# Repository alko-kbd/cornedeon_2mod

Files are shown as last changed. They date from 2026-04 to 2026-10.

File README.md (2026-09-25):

# Cornedeon v2mod Keyboard

Modular Cornedeon split keyboard.

Keyboard Maintainer: [alko](https://github.com/alko-kbd/cornedeon_2mod) [alko-kbd@alk0.ru](mailto:alko-kbd@alk0.ru)

Web Site: [cornedeon.ru](https://cornedeon.ru)

Hardware Supported: Handwired, RP2040, Trackpads, Trackpoints, Joystick.

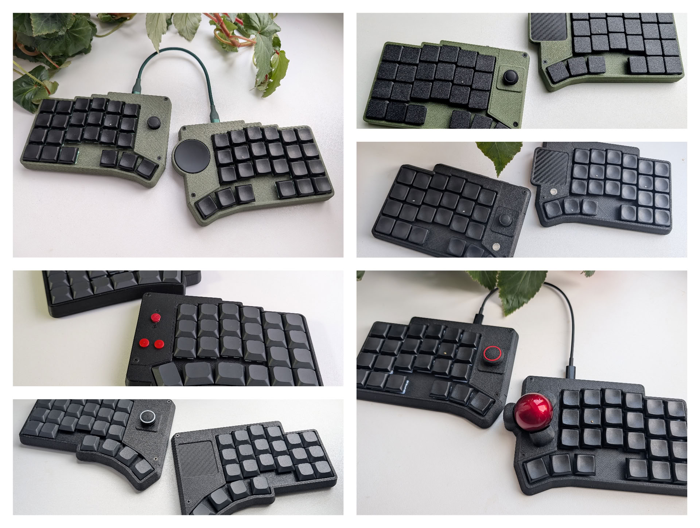
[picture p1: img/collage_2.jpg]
Cornedeon 2MOD


**Revision 2mod**

Support for custom modules on same case, as trackpoint, trackpad, trackball, encoders, joystick etc.

**Build**

#>git clone --recurse-submodules https://github.com/vial-kb/vial-qmk.git

Prepare [build environment](https://get.vial.today/docs/porting-to-vial.html).

Clone this repository to vial-qmk/keyboards/alko.

#>qmk compile -kb alko/cornedeon_2mod -km vial

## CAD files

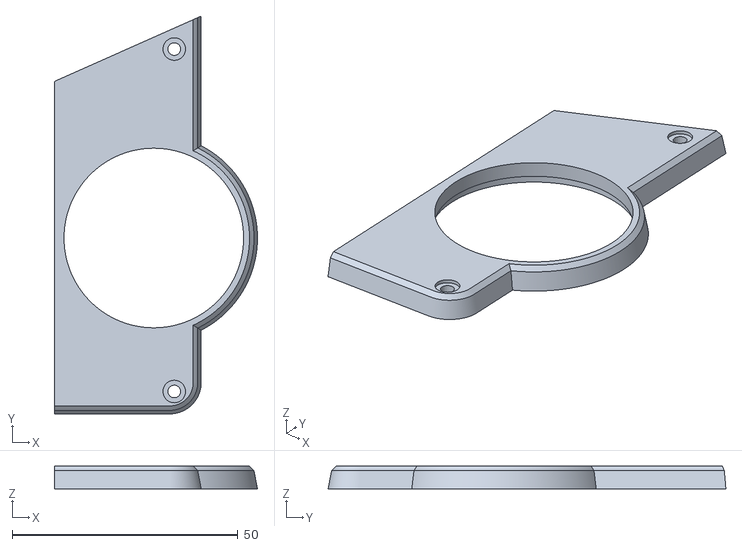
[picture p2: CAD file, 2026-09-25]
case/v3_cirque/cornedeon_2m_choc_cirque_right.stl
45.0 x 88.1 x 5.00

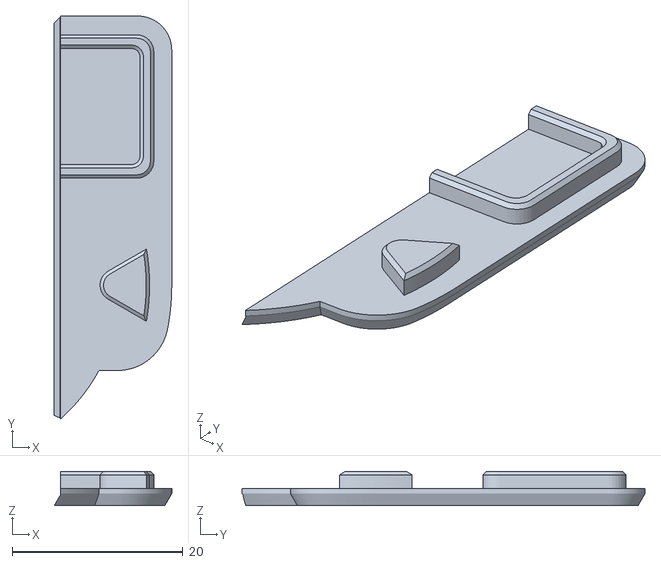
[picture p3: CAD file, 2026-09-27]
case/v4_joy_tps43_tball/cornedeon_2m_tball_stub_v2.stl
13.8 x 47.2 x 4.00

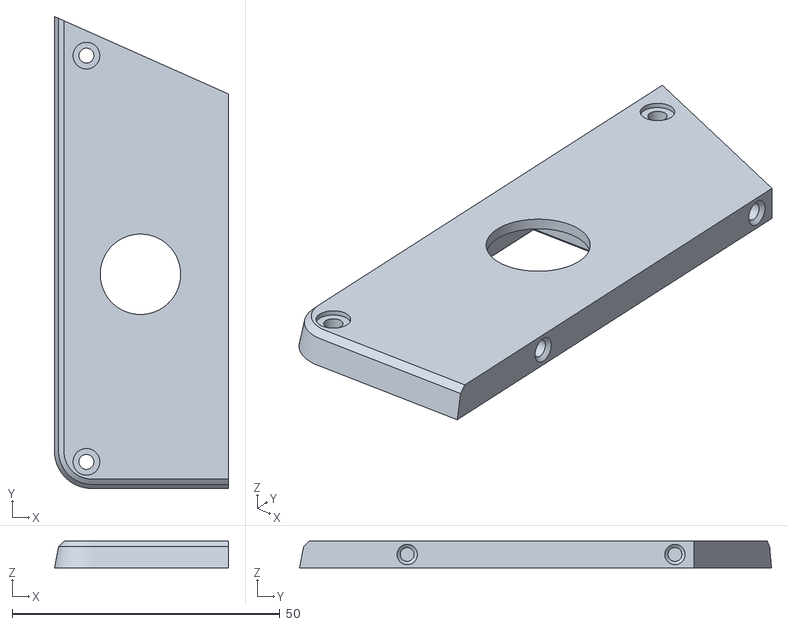
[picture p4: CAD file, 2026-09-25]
case/v3_cirque/cornedeon_2m_choc_switch_left.stl
32.5 x 88.1 x 5.00

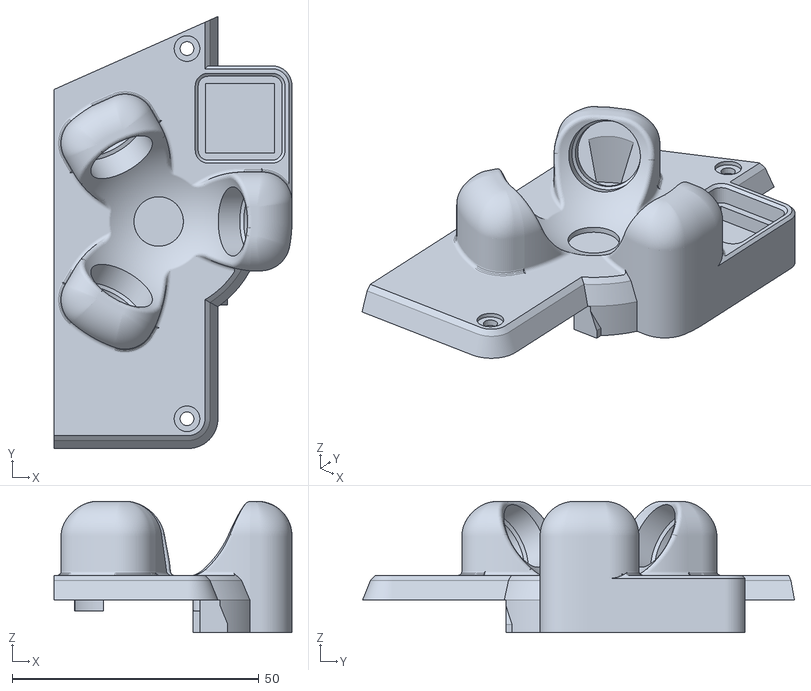
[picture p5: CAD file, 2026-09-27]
case/v4_joy_tps43_tball/cornedeon_2m_tball_v2_right.stl
48.2 x 87.5 x 26.6

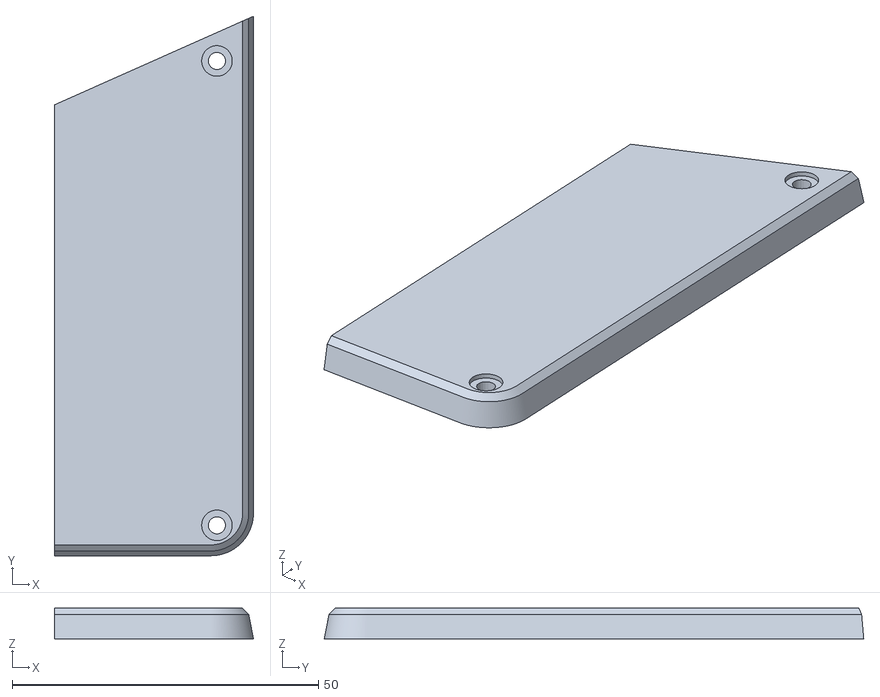
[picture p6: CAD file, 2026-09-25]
case/v3_cirque/cornedeon_2m_choc_stub_right.stl
32.5 x 88.1 x 5.00

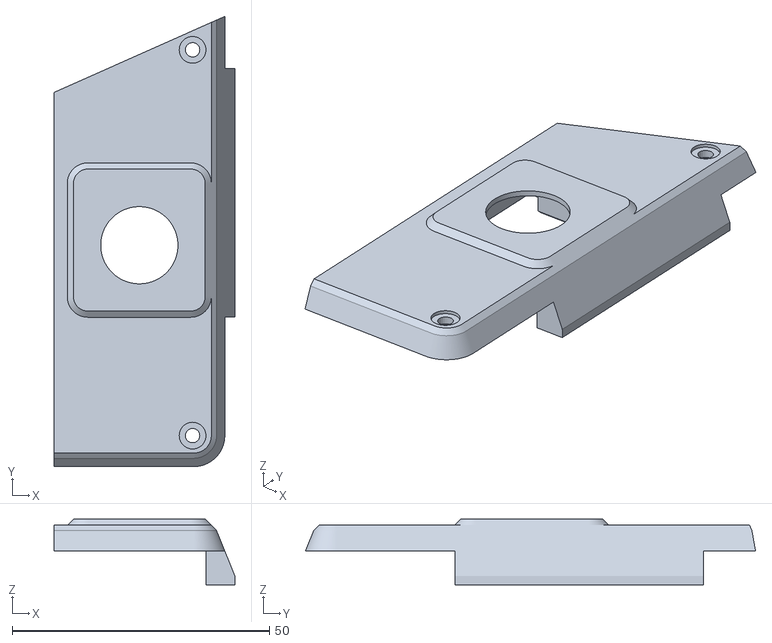
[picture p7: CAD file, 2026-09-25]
case/v4_joy_tps43_tball/cornedeon_2m_joy_left.stl
35.2 x 87.5 x 12.8

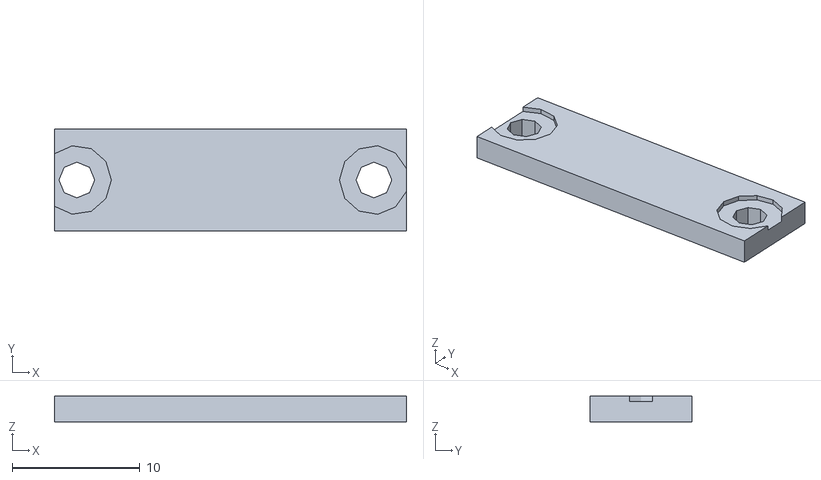
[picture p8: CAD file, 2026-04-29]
case/v3_cirque/switch_bar.stl
27.6 x 8.00 x 2.00

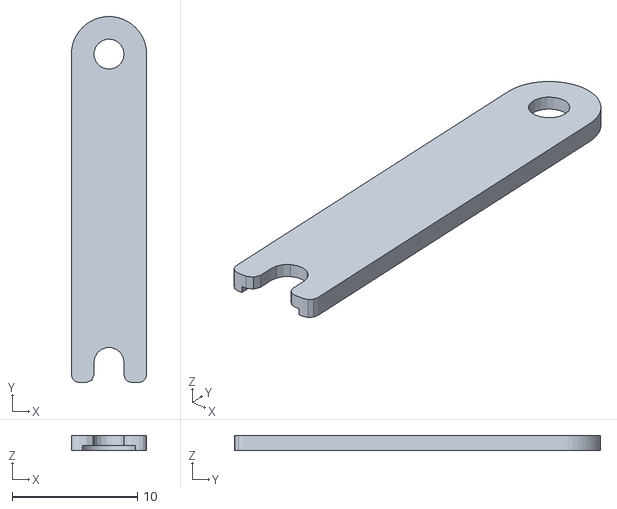
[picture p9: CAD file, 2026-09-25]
case/v4_joy_tps43_tball/joy_bar.stl
6.00 x 29.2 x 1.20

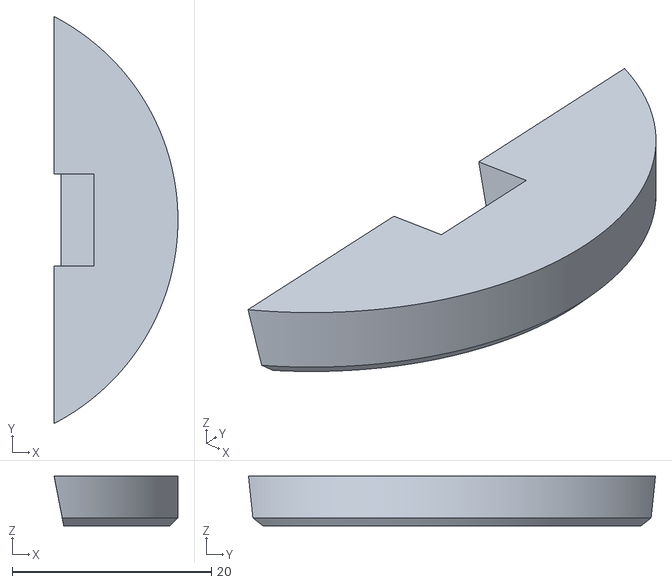
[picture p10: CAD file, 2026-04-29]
case/v3_cirque/cornedeon_2m_choc_cirque_bottom.stl
12.4 x 40.8 x 5.00

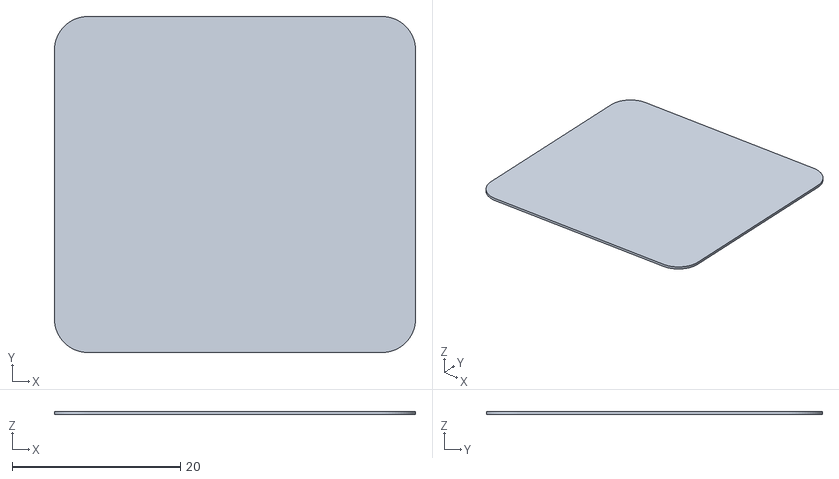
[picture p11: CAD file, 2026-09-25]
case/v4_joy_tps43_tball/tps43_pad.stl
43.0 x 40.0 x 0.4

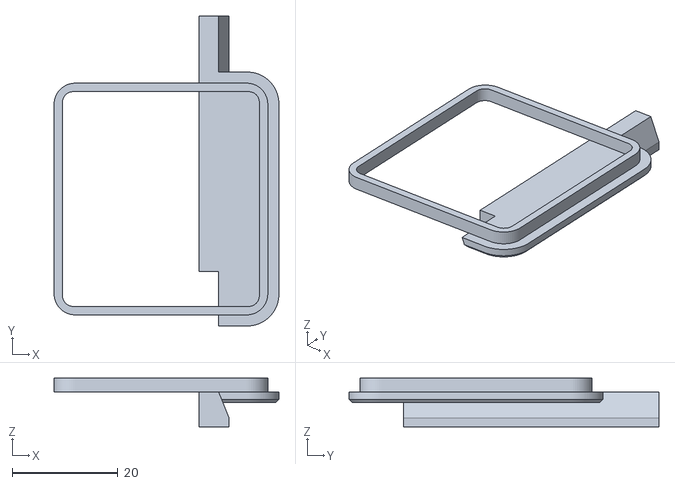
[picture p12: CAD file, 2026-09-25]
case/v4_joy_tps43_tball/cornedeon_2m_tps43_stub.stl
42.5 x 58.6 x 9.20

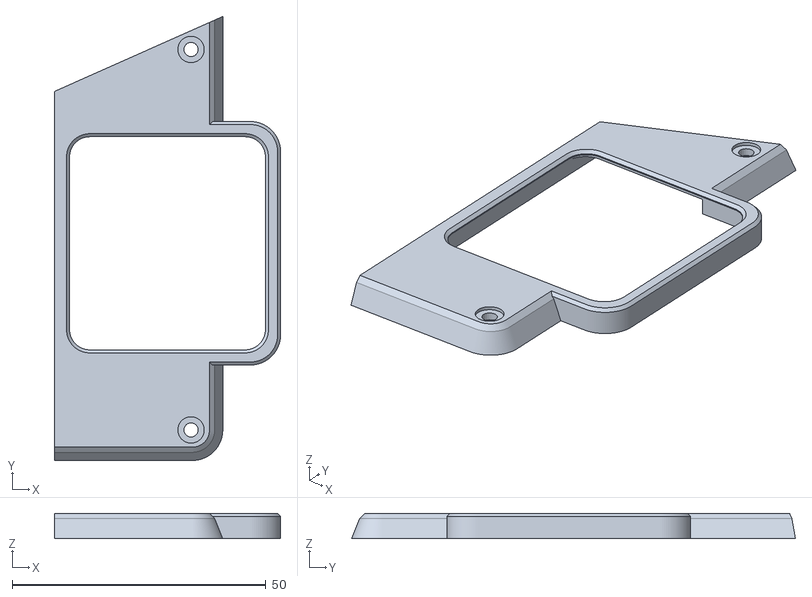
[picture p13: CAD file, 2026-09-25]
case/v4_joy_tps43_tball/cornedeon_2m_tps43.stl
44.6 x 87.5 x 5.00

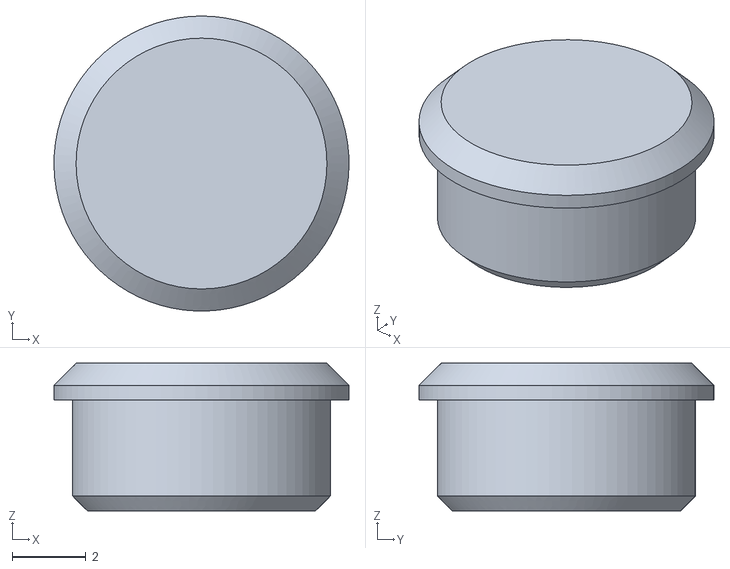
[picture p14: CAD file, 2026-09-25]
case/v4_joy_tps43_tball/led.stl
8.00 x 8.00 x 4.00

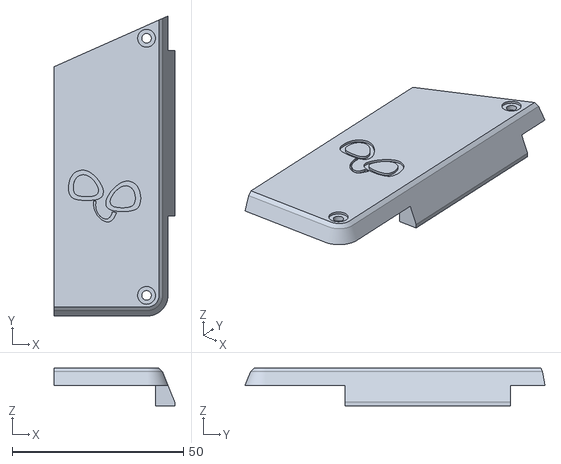
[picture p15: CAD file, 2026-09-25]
case/v4_joy_tps43_tball/cornedeon_2m_stub.stl
35.2 x 87.5 x 11.0

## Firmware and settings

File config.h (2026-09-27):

// Copyright 2024 QMK
// SPDX-License-Identifier: GPL-2.0-or-later

#pragma once

#define DEBOUNCE 5

#define SPLIT_TRANSACTION_IDS_KB SYNC_JOYSTICK_TR_ID
// Shared memory
//#define SPLIT_TRANSPORT_MIRROR --> keyboard.json split.transport.sync.matrix_state
//#define SPLIT_USER_STATE_SIZE sizeof(joystick_state)

//#define SPLIT_ACTIVITY_ENABLE
//#define POINTING_DEVICE_COMBINED
#define SPLIT_POINTING_ENABLE
#define POINTING_DEVICE_RIGHT
#define POINTING_DEVICE_GESTURES_SCROLL_ENABLE
//#define TRACKPAD_ENABLE
#define TRACKBALL_ENABLE
#define TRACKBALL_RIGHT


// === Trackpad
#ifdef TRACKPAD_ENABLE
#define AZOTEQ_IQS5XX_TPS43
#define AZOTEQ_IQS5XX_ROTATION_270
#define AZOTEQ_IQS5XX_TAP_ENABLE true
#define AZOTEQ_IQS5XX_TWO_FINGER_TAP_ENABLE true
#define AZOTEQ_IQS5XX_PRESS_AND_HOLD_ENABLE true
//#define AZOTEQ_IQS5XX_ZOOM_ENABLE
#define AZOTEQ_IQS5XX_SCROLL_ENABLE true
//#define CIRQUE_PINNACLE_DIAMETER_MM 35
//#define CIRQUE_PINNACLE_TAP_ENABLE
//#define CIRQUE_PINNACLE_CURVED_OVERLAY
//#define CIRQUE_PINNACLE_SECONDARY_TAP_ENABLE

#define I2C_DRIVER I2CD1
#define I2C1_SDA_PIN GP10
#define I2C1_SCL_PIN GP11
#endif // TRACKPAD_ENABLE

// === Trackball ===
#ifdef TRACKBALL_ENABLE
#define SPI_DRIVER SPID1
#define SPI_SCK_PIN GP10
#define SPI_MOSI_PIN GP11
#define SPI_MISO_PIN GP12
#define PMW33XX_CS_PIN GP13

/* Optional. */
#define PMW33XX_CPI 1600      // The CPI range is 100-12000, in increments of 100. Defaults to 1600 CPI.
#define PMW33XX_CLOCK_SPEED 2000000 // Sets the clock speed that the sensor runs at. Defaults to 2000000
#define MOUSE_EXTENDED_REPORT // Use -32767 to 32767, instead of just -127 to 127.

#define POINTING_DEVICE_ROTATION_90
#define POINTING_DEVICE_INVERT_X
//#define POINTING_DEVICE_INVERT_Y

/* Scroll */
#define SCROLL_ENABLE
#define SCROLL_LAYER 1
#define SCROLL_DIVISOR 50
//#define SCROLL_X
#define SCROLL_Y

#endif // TRACKBALL_ENABLE

// Split driver = vendor
#define SERIAL_PIO_USE_PIO0
#define SERIAL_USART_FULL_DUPLEX
#define SERIAL_USART_RX_PIN GP1
#define SERIAL_USART_TX_PIN GP0

// RP2040- and hardware-specific config
#define RP2040_BOOTLOADER_DOUBLE_TAP_RESET // Activates the double-tap behavior
#define RP2040_BOOTLOADER_DOUBLE_TAP_RESET_TIMEOUT 500U
#define PICO_XOSC_STARTUP_DELAY_MULTIPLIER 64

#define CUSTOM_JOYSTICK_ENABLE
#define JOYSTICK_LEFT

// Min 0, max 6: X, Y, Z, Rx, Ry, Rz
#ifdef CUSTOM_JOYSTICK_ENABLE
  #define JOYSTICK_AXIS_COUNT 2
  #define JOYSTICK_AXIS_X_PIN GP29
  #define JOYSTICK_AXIS_Y_PIN GP28
  //#define JOYSTICK_INVERT_X_AXIS
  #define JOYSTICK_INVERT_Y_AXIS
  // Min 8, max 16
  #define JOYSTICK_AXIS_RESOLUTION 10
  // Min 0, max 32
  #define JOYSTICK_BUTTON_COUNT 1
  #define JOYSTICK_BUTTON_PIN GP11
#endif

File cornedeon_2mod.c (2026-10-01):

#ifdef __INTELLISENSE__
    #include "quantum.h"
    #include "info_config.h"
    #include "default_keyboard.h"
    #include "config.h"
    #include "debug.h"
#else
    #include QMK_KEYBOARD_H
#endif // __INTELLISENSE__
#ifdef VIAL_ENABLE
    #include "dynamic_keymap.h"
#endif // VIAL_ENABLE
#ifdef DEBUG_ENABLE
    #include "debug.h"
#endif
#ifdef CONSOLE_ENABLE
    #include "print.h"
#endif // CONSOLE_ENABLE
#include "analog.h"
#include "transactions.h"
#include "split_util.h"

#ifdef CUSTOM_JOYSTICK_ENABLE

typedef struct {
    int input_pin;
    uint16_t min_value;
    uint16_t mid_value;
    uint16_t max_value;
} custom_joystick_config_t;

typedef struct {
    uint8_t button_state;
    int16_t delta_x;
    uint16_t delay_x;
    int16_t delta_y;
    uint16_t delay_y;
} custom_joystick_state_t;

//static int button_state = 0;
custom_joystick_config_t joystick_config[JOYSTICK_AXIS_COUNT] = {
    { JOYSTICK_AXIS_X_PIN, 45, 516, 930 },
    { JOYSTICK_AXIS_Y_PIN, 85, 516, 970 }
};

custom_joystick_state_t prev_joystick_state = { 0, 0, 0, 0, 0 };
custom_joystick_state_t joystick_state = { 0, 0, 0, 0, 0 };

static bool is_joystick_side = false;

// Joystick threshold and repeating
#define JS_THRESHOLD 80           // Deathzone center
#define JS_MAX_SPEED_DELAY 15     // Faster - min delay
#define JS_MIN_SPEED_DELAY 200    // Slower - max delay

// Joystick mapped matrix keys
#define JS_KEY_ROW        4
#define JS_KEY_COL_LEFT   0
#define JS_KEY_COL_UP     1
#define JS_KEY_COL_DOWN   2
#define JS_KEY_COL_RIGHT  3
#define JS_KEY_COL_BUTTON 4

void init_joystick(void) {
    is_joystick_side = 
    #ifdef JOYSTICK_LEFT
        is_keyboard_left();
    #else
        !is_keyboard_left();
    #endif
    uprintf("is_joystick_side: %d\n", is_joystick_side);
    if (is_joystick_side) {
        dprint("init joystick\n");
        setPinInputHigh(JOYSTICK_BUTTON_PIN);
        joystick_config[0].mid_value = analogReadPin(joystick_config[0].input_pin);
        joystick_config[1].mid_value = analogReadPin(joystick_config[1].input_pin);
    }
}

// Функция для маппинга значений
// Преобразует отклонение в задержку (мс)
uint16_t get_joystick_delay(int16_t diff, custom_joystick_config_t* cfg) {
    int abs_diff = abs(diff);
    int max = 512;
    if (diff > 0)
        max = cfg->max_value - cfg->mid_value;
    else
        max = cfg->mid_value - cfg->min_value;
    if (abs_diff < JS_THRESHOLD)  // In deathzone
        return 0;
    uint16_t delay = JS_MIN_SPEED_DELAY - ((abs_diff - JS_THRESHOLD) * (JS_MIN_SPEED_DELAY - JS_MAX_SPEED_DELAY) / (max - JS_THRESHOLD));
    return delay;
}

//extern uint16_t keymaps[][MATRIX_ROWS][MATRIX_COLS];

void update_joystick_state(void) {
    prev_joystick_state = joystick_state;

    // Read button state
    joystick_state.button_state = readPin(JOYSTICK_BUTTON_PIN);

    // Read axis values
    int16_t x_value = analogReadPin(joystick_config[0].input_pin);
    joystick_state.delta_x = x_value - joystick_config[0].mid_value;
    joystick_state.delay_x = get_joystick_delay(joystick_state.delta_x, &joystick_config[0]);

    int16_t y_value = analogReadPin(joystick_config[1].input_pin);
    joystick_state.delta_y = y_value - joystick_config[1].mid_value;
    joystick_state.delay_y = get_joystick_delay(joystick_state.delta_y, &joystick_config[1]);

    // For calibrate
    //uprintf("Joystick raw: X=%d Y=%d\n", x_value, y_value);

    //if (x_delay > 0 || y_delay > 0)
    //    uprintf("Joystick: x_delay=%d y_delay=%d\n", x_delay, y_delay);
}

// Axis timers
static uint16_t timer_x = 0;
static uint16_t timer_y = 0;

extern const uint16_t keymaps[][MATRIX_ROWS][MATRIX_COLS];

void process_joystick_state(void) {
    // Button state
    if (joystick_state.button_state == 0 && joystick_state.button_state != prev_joystick_state.button_state) {
        uint8_t layer = get_highest_layer(layer_state);
        uint16_t keycode = KC_NO;
        #ifdef VIAL_ENABLE
            keycode = dynamic_keymap_get_keycode(layer, JS_KEY_ROW, JS_KEY_COL_BUTTON);
        #endif
        if (keycode == KC_NO) {
            keycode = keymaps[layer][JS_KEY_ROW][JS_KEY_COL_BUTTON];
        }
        tap_code16(keycode);
    }

    // X axis
    if (joystick_state.delay_x > 0 && timer_elapsed(timer_x) > joystick_state.delay_x) {
        uint8_t layer = get_highest_layer(layer_state);
        int key_idx =
            #ifdef JOYSTICK_INVERT_X_AXIS
                (joystick_state.delta_x > 0)
            #else
                (joystick_state.delta_x < 0)
            #endif
            ? JS_KEY_COL_LEFT : JS_KEY_COL_RIGHT;
        uint16_t keycode = KC_NO;
        #ifdef VIAL_ENABLE
            keycode = dynamic_keymap_get_keycode(layer, JS_KEY_ROW, key_idx);
        #endif
        if (keycode == KC_NO) {
            keycode = keymaps[layer][JS_KEY_ROW][key_idx];
        }
        tap_code16(keycode);
        timer_x = timer_read();
    }

    // Y axis - inverted
    if (joystick_state.delay_y > 0 && timer_elapsed(timer_y) > joystick_state.delay_y) {
        uint8_t layer = get_highest_layer(layer_state);
        int key_idx =
            #ifdef JOYSTICK_INVERT_Y_AXIS
                (joystick_state.delta_y < 0)
            #else
                (joystick_state.delta_y > 0)
            #endif
            ? JS_KEY_COL_UP : JS_KEY_COL_DOWN;
        uint16_t keycode = KC_NO;
        #ifdef VIAL_ENABLE
            keycode = dynamic_keymap_get_keycode(layer, JS_KEY_ROW, key_idx);
        #endif
        if (keycode == KC_NO) {
            keycode = keymaps[layer][JS_KEY_ROW][key_idx];
        }
        tap_code16(keycode);
        timer_y = timer_read();
    }

}

#endif // CUSTOM_JOYSTICK_ENABLE

#ifdef TRACKBALL_ENABLE

static bool is_trackball_side = false;

void init_trackball(void) {
    is_trackball_side = 
    #ifdef TRACKBALL_RIGHT
        !is_keyboard_left();
    #else
        is_keyboard_left();
    #endif
    uprintf("is_trackball_side: %d\n", is_trackball_side);
}

void pointing_device_init_user(void) {
    if (is_trackball_side) {
        pmw33xx_set_cpi(0, PMW33XX_CPI);
        uprintf("trackball init CPI:: %d\n", PMW33XX_CPI);
    }
}

static int32_t scroll_accum_y = 0;
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

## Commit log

2026-09-27 +trackball button
2026-09-27 +trackball module
    [cornedeon_2m_joy_left.stl, cornedeon_2m_stub.stl, cornedeon_2m_tball_stub_v2.stl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]
